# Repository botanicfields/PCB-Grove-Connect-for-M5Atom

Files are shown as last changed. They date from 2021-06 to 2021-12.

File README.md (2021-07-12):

# PCB-Grove-for-M5Atom
a PCB to add 3 Grove Connectors to M5Atom

# M5Atom 用 GROVE コネクタ基板

M5Atom のピンソケット (GPIO) を GROVE コネクタに変換する基板です。
GROVE ケーブルによるデバイスの接続が簡単になります。

委託販売（スイッチサイエンス）：  
https://www.switch-science.com/catalog/7309/

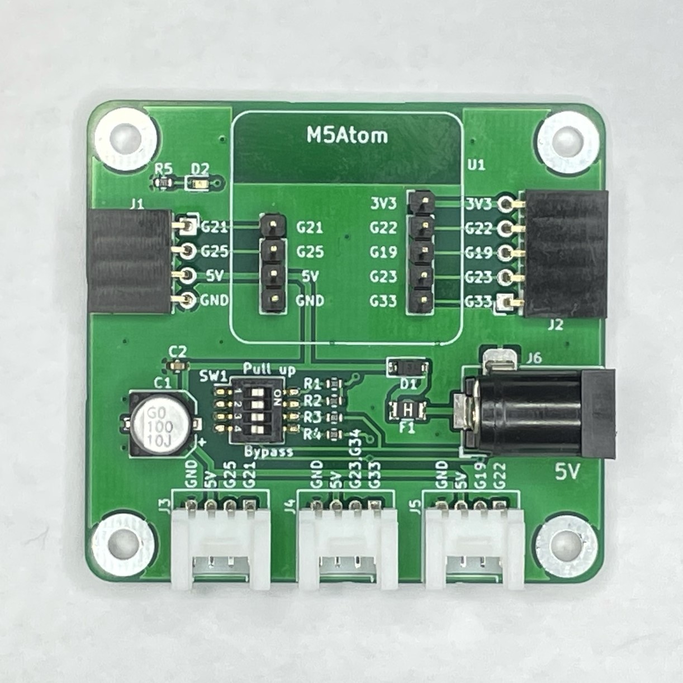
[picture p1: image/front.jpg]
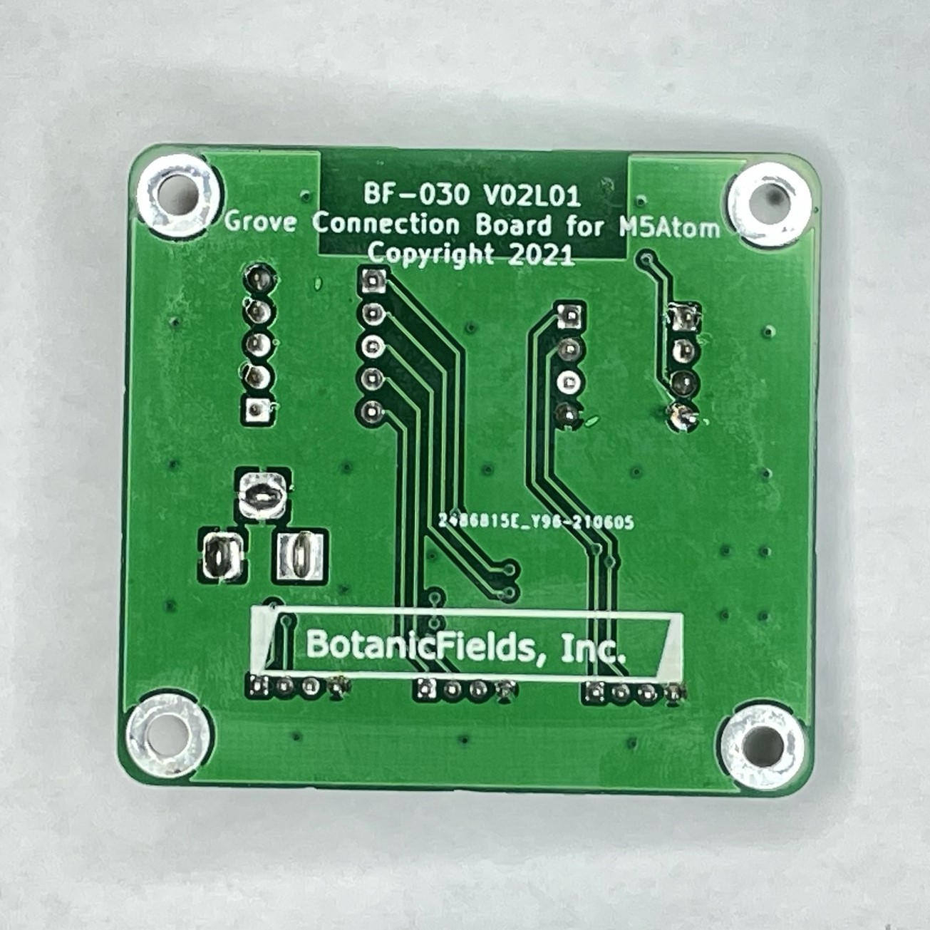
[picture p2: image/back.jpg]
 

## 1. 特徴

- 基板上のピンヘッダに M5Atom Lite/Matrix を直接接続できます。
- M5Atom の GPIO を GROVE コネクタ 3 個で取り出せます。M5Atom の Grove ポートと合わせて計 4 ポートとなります。
- M5Atom のピンソケットを、基板上のピンソケットから取り出せます。
- DC ジャック (5V) があり、USB-C ケーブルと同時または単独でも給電できます。DCジャックからの電源にはフューズがあります。
- ディップスイッチで、一部プルアップ抵抗/保護抵抗の接続/バイパスができます。

※ 動作中の電源の抜き差し (USB-C / DC ジャック) は、動作継続を保証できません。

## 2. ご注意

- M5Atom は付属しません。
- AC アダプタは付属しません。
- GROVE ケーブルは付属しません。
- ディップスイッチの切り替えには、ピンセット等が必要です。
- プリント基板単体の完成品です。ケースや足は付属しません。裏面からピンが飛び出しています。絶縁材や四隅の穴にスペーサを取り付けるなどして、負傷、静電気破壊、机などの傷を防止してください。

## 使用例
「ENV ユニット」(I2C)、「M5 用光センサ・押しボタン 5 基板」(アナログ)、「DFPlayer-Mini用 Grove 接続基板」(UART) を同時接続し、USB-C または DC 5V 電源を接続しています。動作に使用したプログラム BF-030.ino は、温度・湿度・気圧・周囲の明るさをシリアルモニタに定期的に表示する一方、押しボタンで楽曲の演奏を制御（次の曲、前の曲、音量増、音量減、USB/microSD 切替）できます。

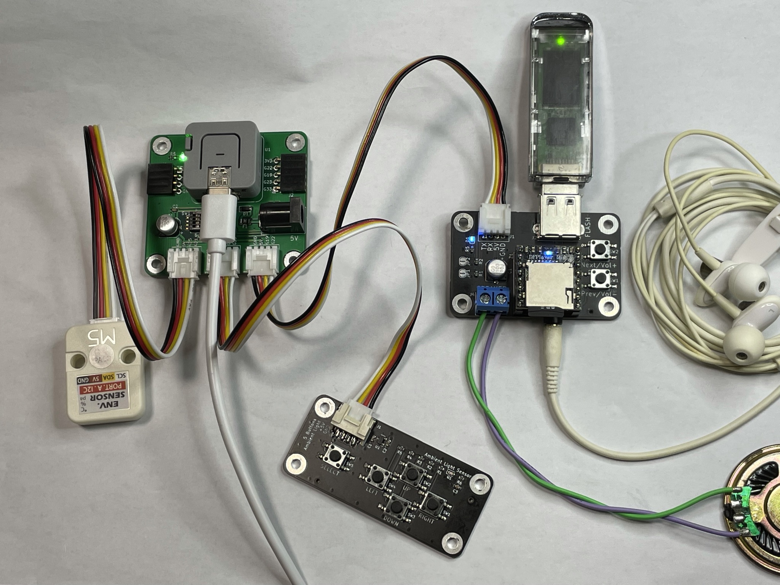
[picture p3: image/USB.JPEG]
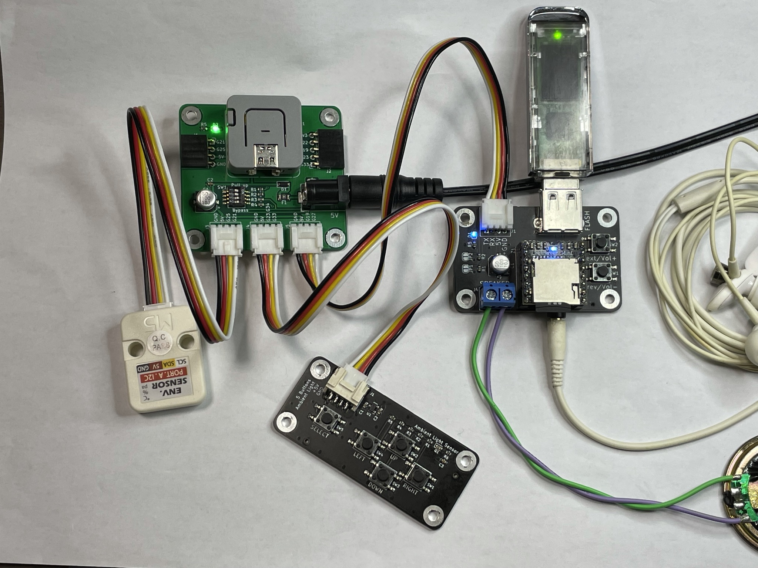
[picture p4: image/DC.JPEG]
 

## 3. 詳細

回路図をご確認ください。

| GROVE | pin 1 | pin 2 | pin 3 | pin 4 | 想定用途 | 備考 |
|:-:|:-|:-|:-:|:-:|:-:|:-:|
|  J3  | G21 (SCL) | G25 (SDA) | +5V | GND  | I2C | プルアップ抵抗(*1)設定可 |
|  J4  | G33 | G23, G34 | +5V | GND  | アナログ入力 | - |
|  J5  | G22 (RX) | G19 (TX) | +5V | GND  | シリアル |  保護抵抗(*2)バイパス可 |

(*1) DIP スイッチ 1, 2 を ON にすると、プルアップ抵抗 (10kΩ) が有効となります。I2C では M5Atom 内蔵のプルアップ機能があり、またデバイス側にもプルアップ抵抗があったりするため通常は不要ですが、外付けが必要な場合に使えます。
 
(*2) DIP スイッチ 3, 4 を ON にすると、保護抵抗 (1kΩ) をバイパスします。保護抵抗は、5V 系のシリアルインタフェースを 3.3V 系である M5Atom の RX に接続する場合の過電圧から保護します。3.3V 系との接続では保護抵抗をバイパスできます。3.3V で出力する TX には保護抵抗は不要と考えられますが、実験での接続ミスなどを考慮して使用することもできます。

| DIP スイッチ 番号 | 影響するピン | ON の場合 |
|:-:|:-:|:-:|
| 1 | G21 (SCL) | プルアップ抵抗 (10kΩ) を接続 |
| 2 | G25 (SDA) | プルアップ抵抗 (10kΩ) を接続 |
| 3 | G22 (RX)  | 保護抵抗(1kΩ) をバイパス |
| 4 | G19 (TX)  | 保護抵抗(1kΩ) をバイパス |

DC ジャックからの電源にはフューズ (PTC リセッタブル、保持電流 1.1A, トリップ電流 2.2A) があります。ちなみに M5Atom 内部には 5V 出力に 0.5A のフューズがあります。

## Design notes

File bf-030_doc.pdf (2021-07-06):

BF-030 V02

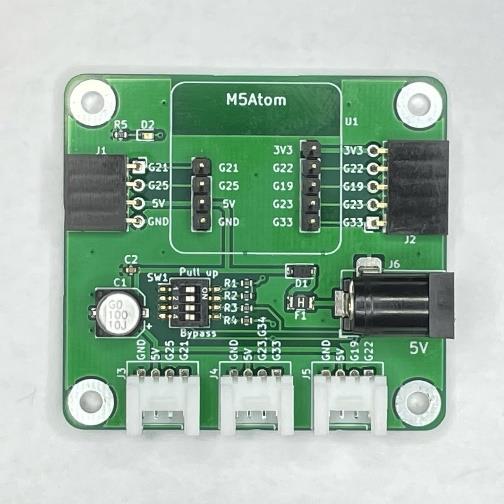
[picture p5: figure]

Copyright 2021 BotanicFields, Inc. 1

## M5Atom 用 GROVE コネクタ基板

M5Atom のピンソケット(GPIO)を GROVE コネクタに変換する基板 です。 GROVE ケーブルによるデバイスの接続が簡単になります。

1. 内容物（各１）
(1) プリント基板
(2) 説明書（本書）
※M5Atom、GROVE ケーブル、AC アダプタ等は付属しません。
2. ご使用方法
(1) M5Atom の取り付け
ピンヘッダに差し込みます。間違いが無いことを目視で再確認してから電源を供給してください。
(2) 電源について
DC ジャックは 5V 専用です。DC ジャックと USB-C ケーブルを同時または単独で給電できます。DC ジャックにはフューズ（PTC リセッタブル、保持電流 1.1A, トリップ電流 2.2A）があります。
(3) GROVE コネクタのピン
(4) ディップスイッチ
3. ご注意
(1) ディップスイッチの切り換えにはピンセット等が必要です。
(2) 稼働中の DC ジャックや USB-C ケーブルの抜き差しは、継続動作を保証できません。
(3) プリント基板単体の完成品です。ケースや足はありません。部品の足が剥き出しのため、絶縁材や四隅の 穴にスペーサを取り付けるなどして、負傷、静電気破壊、机の傷などを防止ください。
4. 参考情報
GitHub 「botanicfields/PCB-Grove-for-M5Atom」 https://github.com/botanicfields/PCB-Grove-for-M5Atom
GROVE | pin 1 | pin 2 | pin 3 | pin 4 | 想定用途 | 備考
J3 | G21 (SCL) | G25 (SDA) | +5V | GND | I2C | プルアップ抵抗(*1)設定可
J4 | G33 | G23, G34 | +5V | GND | アナログ入力 | -
J5 | G22 (RX) | G19 (TX) | +5V | GND | シリアル | 保護抵抗(*2)バイパス可
DIP スイッチ番号 | 影響するピン | ON の場合
1 | G21 (SCL) | プルアップ抵抗(10kΩ)を接続
2 | G25 (SDA) | プルアップ抵抗(10kΩ)を接続
3 | G22 (RX) | 保護抵抗(1kΩ)をバイパス
4 | G19 (TX) | 保護抵抗(1kΩ)をバイパス

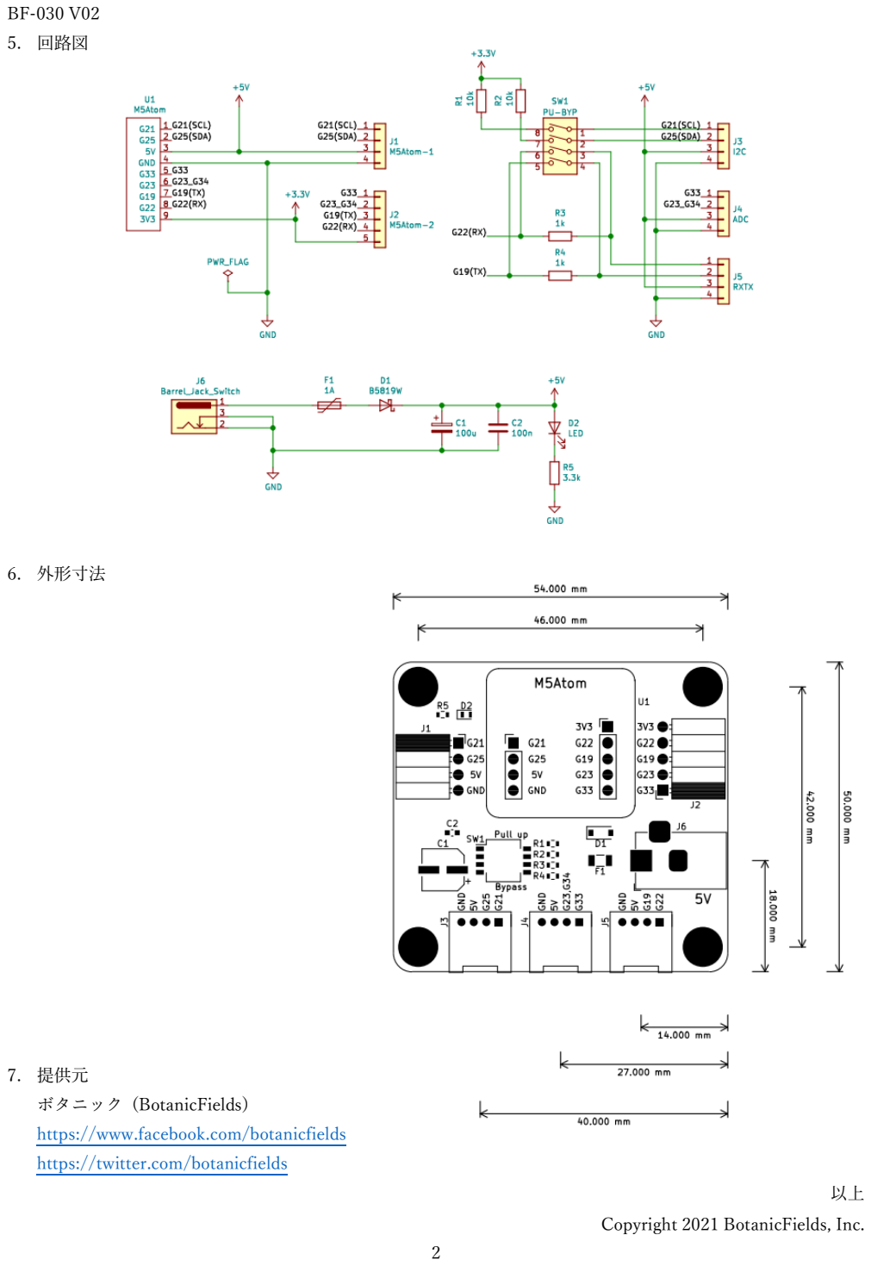
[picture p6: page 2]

BF-030 V02

Copyright 2021 BotanicFields, Inc. 2

5. 回路図
6. 外形寸法
7. 提供元
ボタニック (BotanicFields)
https://www.facebook.com/botanicfieldshttps://twitter.com/botanicfields
以上

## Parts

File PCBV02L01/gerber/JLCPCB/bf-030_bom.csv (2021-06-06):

Comment | Designator | Footprint | LCSC
100u | C1 | bf:BF@CP_Elec_6.3x5.3 | C134749
100n | C2 | bf:BF@C_0603_1608Metric | C14663
B5819W | D1 | bf:BF@D_SOD-123 | C8598
LED | D2 | bf:BF@LED_0603_1608Metric | C72043
1A | F1 | bf:BF@Fuse_1206_3216Metric | C126818
M5Atom-1 | J1 | Connector_PinSocket_2.54mm:PinSocket_1x04_P2.54mm_Horizontal
M5Atom-2 | J2 | Connector_PinSocket_2.54mm:PinSocket_1x05_P2.54mm_Horizontal
I2C | J3 | OPL_Connector:HW4-2.0-90D
ADC | J4 | OPL_Connector:HW4-2.0-90D
RXTX | J5 | OPL_Connector:HW4-2.0-90D
Barrel_Jack_Switch | J6 | bf:BF@BarrelJack_Horizontal
10k | R1,R2 | bf:BF@R_0603_1608Metric | C25804
1k | R3,R4 | bf:BF@R_0603_1608Metric | C21190
3.3k | R5 | bf:BF@R_0603_1608Metric | C22978
PU-BYP | SW1 | Button_Switch_SMD:SW_DIP_SPSTx04_Slide_KingTek_DSHP04TS_W7.62mm_P1.27mm | C319050
M5Atom | U1 | bf:BF@M5Atom

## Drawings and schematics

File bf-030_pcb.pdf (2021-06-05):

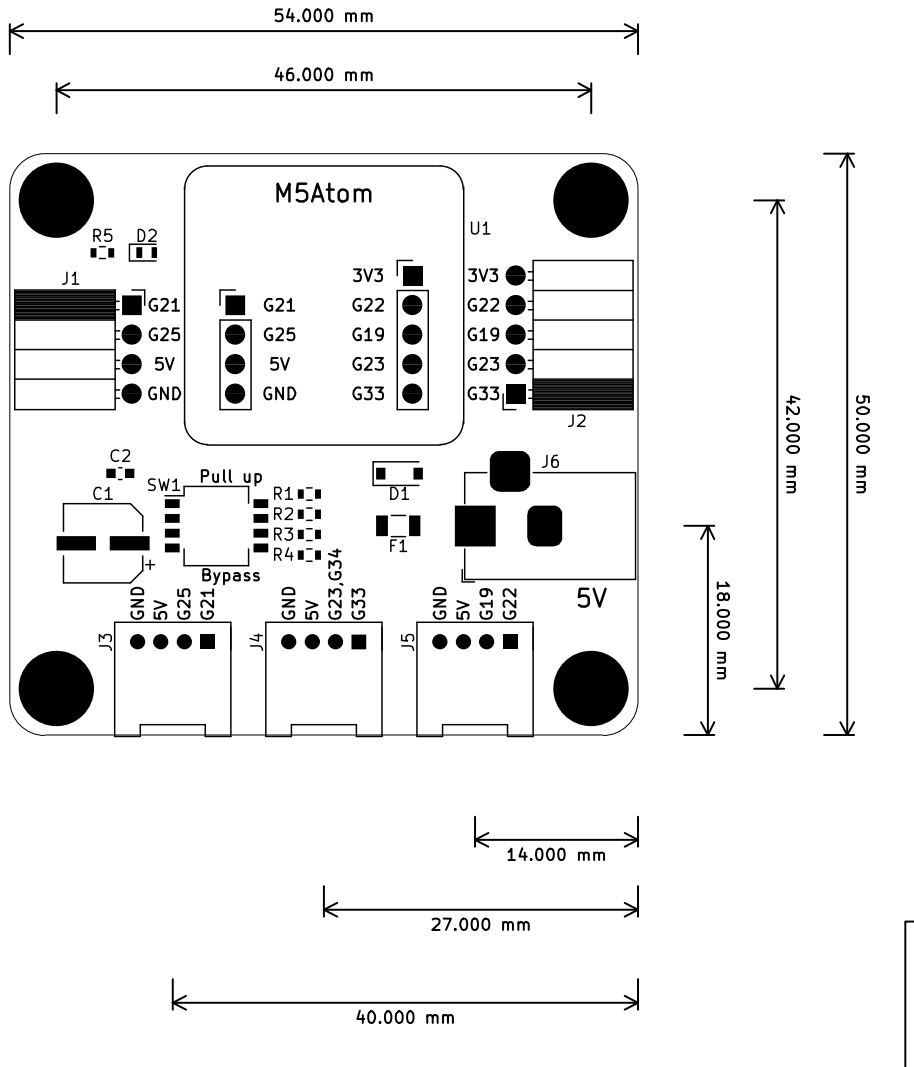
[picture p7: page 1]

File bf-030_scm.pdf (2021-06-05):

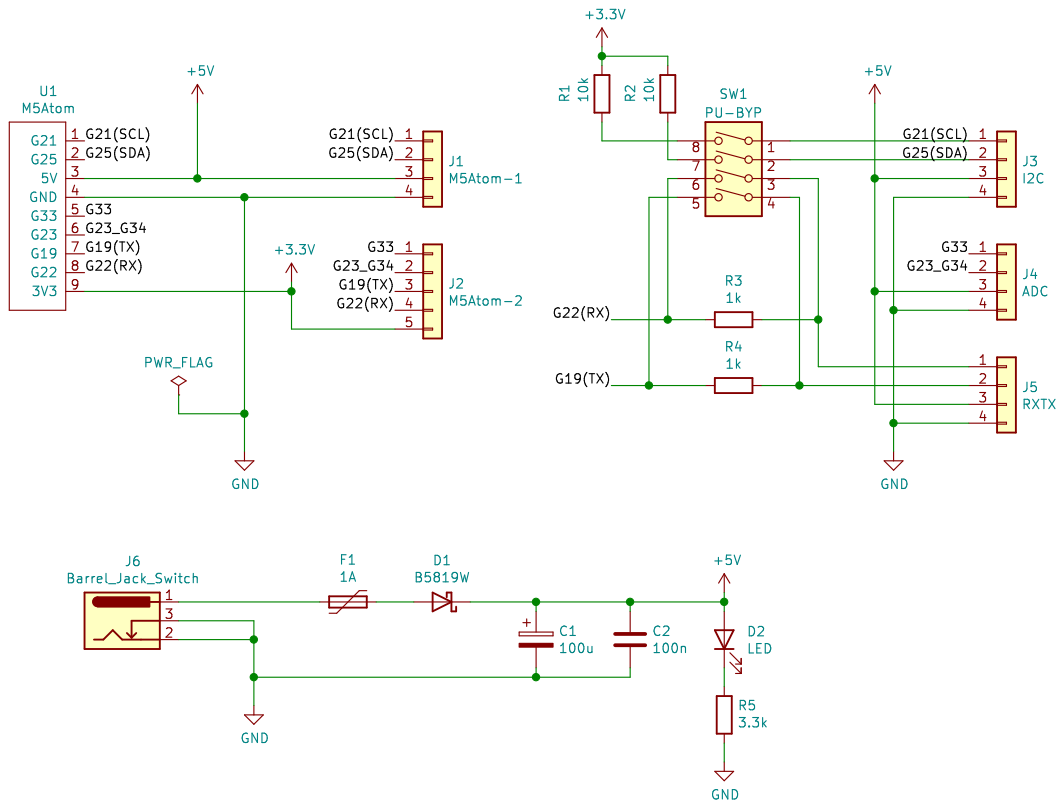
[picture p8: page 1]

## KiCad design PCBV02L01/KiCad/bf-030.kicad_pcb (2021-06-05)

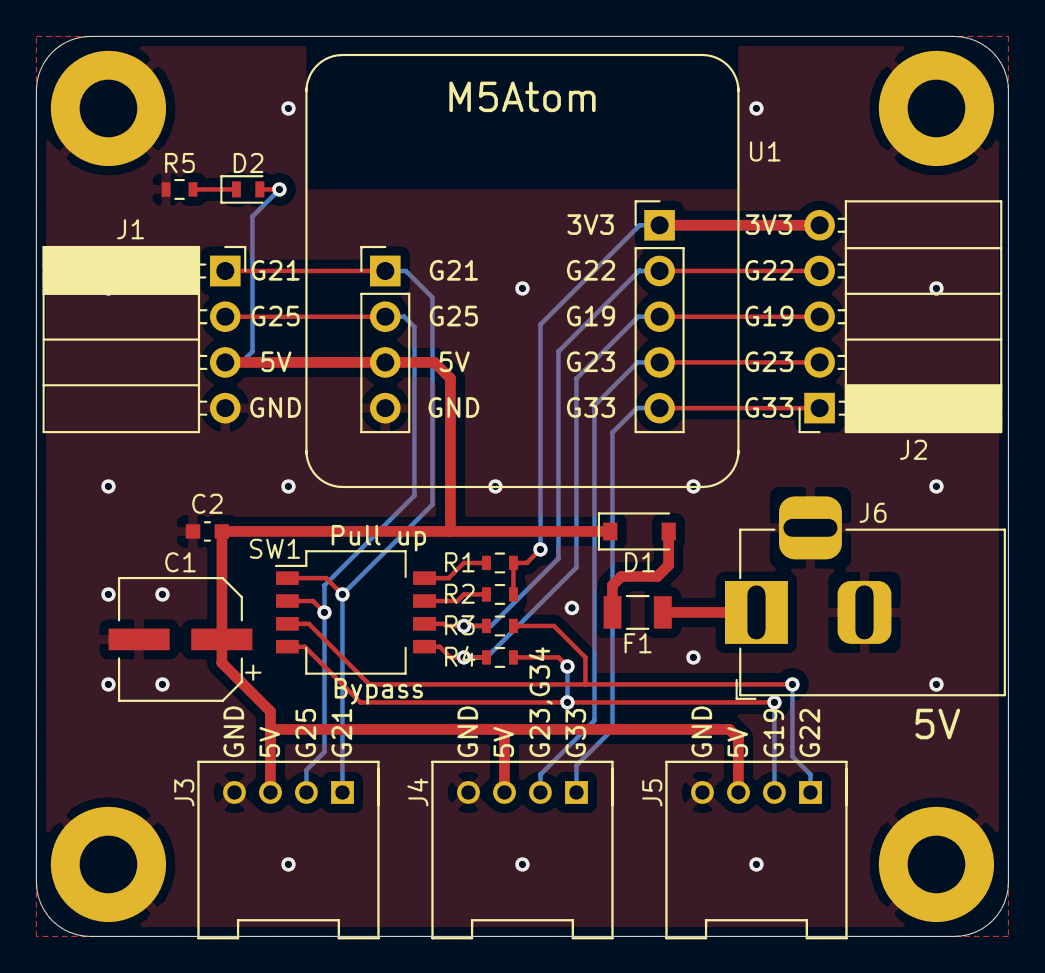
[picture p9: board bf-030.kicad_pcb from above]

Board: 2 copper layers, 54.0 x 50.0 mm, 18 parts (0 on the bottom side), 16 nets.

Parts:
C1: 100u; BF@CP_Elec_6.3x5.3
C2: 100n; BF@C_0603_1608Metric
D1: B5819W; BF@D_SOD-123
D2: LED; BF@LED_0603_1608Metric
F1: 1A; BF@Fuse_1206_3216Metric
J1: M5Atom-1; PinSocket_1x04_P2.54mm_Horizontal
J2: M5Atom-2; PinSocket_1x05_P2.54mm_Horizontal
J3: I2C; HW4-2.0-90D
J4: ADC; HW4-2.0-90D
J5: RXTX; HW4-2.0-90D
J6: Barrel_Jack_Switch; BF@BarrelJack_Horizontal
R1, R2: 10k; BF@R_0603_1608Metric
R3, R4: 1k; BF@R_0603_1608Metric
R5: 3.3k; BF@R_0603_1608Metric
SW1: PU-BYP; SW_DIP_SPSTx04_Slide_KingTek_DSHP04TS_W7.62mm_P1.27mm
U1: M5Atom; BF@M5Atom

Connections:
+3V3: J2.5, R1.1, R2.1, U1.9
+5V: C1.1, C2.1, D1.1, D2.2, J1.3, J3.3, J4.3, J5.3, U1.3
/G19(TX): J2.3, R4.2, SW1.5, U1.7
/G21(SCL): J1.1, J3.1, SW1.1, U1.1
/G22(RX): J2.4, R3.2, SW1.6, U1.8
/G23_G34: J2.2, J4.2, U1.6
/G25(SDA): J1.2, J3.2, SW1.2, U1.2
/G33: J2.1, J4.1, U1.5
GND: C1.2, C2.2, J1.4, J3.4, J4.4, J5.4, J6.2, J6.3, R5.1, U1.4
unnamed: D1.2, F1.1
unnamed: D2.1, R5.2
unnamed: F1.2, J6.1
unnamed: J5.1, R3.1, SW1.3
unnamed: J5.2, R4.1, SW1.4
unnamed: R1.2, SW1.8
unnamed: R2.2, SW1.7

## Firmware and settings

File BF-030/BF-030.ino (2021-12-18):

// copyright 2021 BotanicFields, Inc.
// M5Atom, DFPlayerMini, AdcButton, and ENV unit
//
//    Please install library before compiling:
//    Adafruit BMP280: https://github.com/adafruit/Adafruit_BMP280_Library

#include <M5Atom.h>
#include "DHT12.h"
#include "Adafruit_Sensor.h"
#include <Adafruit_BMP280.h>
#include "BF_DfplayerMini.h"
#include "BF_AdcButton.h"

// for ENV unit
DHT12 dht12;
Adafruit_BMP280 bme;

// for DFplayer-Mini
DfplayerMini Dfpm;
int dfpm_select(0);

void setup()
{
  const bool serial_enable(true);
  const bool i2c_enable(true);
  const bool display_enable(true);
  M5.begin(serial_enable, !i2c_enable, display_enable);
  delay(3000);
  Serial.println("M5Stack begin");

  // Port I2C
  const int wire_scl(21);       // GPIO21
  const int wire_sda(25);       // GPIO25
  const int wire_freq(100000);  // 100kHz
  Wire.begin(wire_sda, wire_scl, wire_freq);
  Serial.println("Wire begin");

  // for ENV unit
  while (!bme.begin(0x76))
    Serial.println("Could not find a valid BMP280 sensor, check wiring!");
  Serial.println("BME begin");

  // Port Analog
  const int analog_port_button_pin(33);  // GPIO33
  const int ambient_light_pin(34);       // GPIO34

  // for ADC Button and Ambient Light
  AdcButtonBegin(analog_port_button_pin);
  ambient_light_sensor.Begin(ambient_light_pin);
  Serial.println("ADC begin");

  // Port UART
  const int serial2_rx(22);  // GPIO22
  const int serial2_tx(19);  // GPIO19
  Serial2.begin(9600, SERIAL_8N1, serial2_rx, serial2_tx);

  // for DFPlayer-Mini
  const bool feedback_enable(true);
  Dfpm.Begin(Serial2, !feedback_enable);
  delay(3000);
  Dfpm.Reset();
}

void loop()
{
  M5.update();
  AdcButtonUpdate();
  Dfpm.Update();

  if (btn_right.wasReleased()) Dfpm.Next();
  if (btn_up.wasReleased())    Dfpm.IncreaseVolume();
  if (btn_down.wasReleased())  Dfpm.DecreaseVolume();
  if (btn_left.wasReleased())  Dfpm.Previous();
  if (btn_select.wasReleased())  // Playing will be stopped by selecting device
    switch (dfpm_select) {
      case  0: Dfpm.SelectDevice(0x01);  dfpm_select = 1;  break;
      case  1: Dfpm.SelectDevice(0x02);  dfpm_select = 0;  break;
      default: dfpm_select = 0;  break;
    }

  static unsigned int ambient_last_ms(0);
  if (millis() - ambient_last_ms > 10000) {  // every 10sec
    float tmp = dht12.readTemperature();
    float hum = dht12.readHumidity();
    float pressure = bme.readPressure();
    int ambient_light = ambient_light_sensor.Read();
    Serial.printf("Temperature: %2.2f*C  Humidity: %0.2f%%  Pressure: %0.2fPa  Ambient light: %d\n", tmp, hum, pressure, ambient_light);
    ambient_last_ms = millis();
  }
}

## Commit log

2021-05-31 New
    First Upload
    [bf-030.kicad_pcb, bf-030.sch, bf-030_bom.csv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]
2021-06-05 V02L01
    revised
    [bf-030.kicad_pcb, bf-030.sch, bf-030_bom.csv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]
2021-06-06 PCB V02L01
    gerber
    [bf-030_bom.csv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]
